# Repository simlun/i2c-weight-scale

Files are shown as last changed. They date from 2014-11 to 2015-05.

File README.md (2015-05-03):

I²C Weight Scale
================

_I²C Weight Scale: strain gauges in a Wheatstone bridge amplified in an
instrumentation amplifier, A/D converted and made available over I²C in a PIC
microcontroller._

I²C slave. Reading from the slave responds with a stable digital representation
of the load on the strain gauges under a hacked ordinary weight scale.

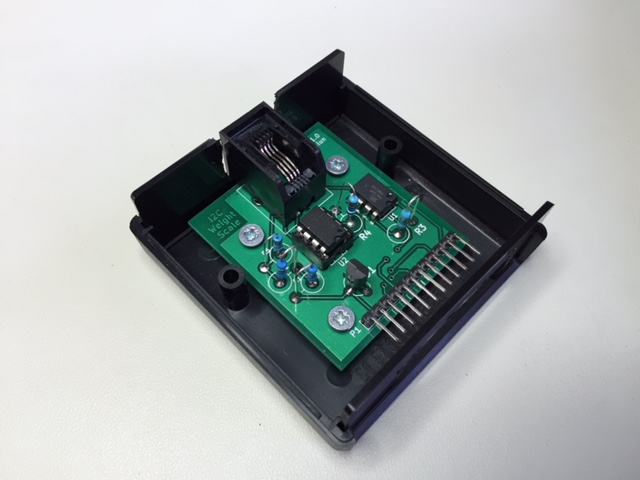
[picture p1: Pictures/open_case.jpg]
Open Case


Schematic
---------

The [KiCad](http://www.kicad-pcb.org/) source files can be found under `PCB/`.
The schematic rendered as a PDF is reached by clicking the PNG below.. The
KiCad project depends on [my component library](https://github.com/simlun/kicad-library-by-simlun)
which should be checked out alongside this repository.

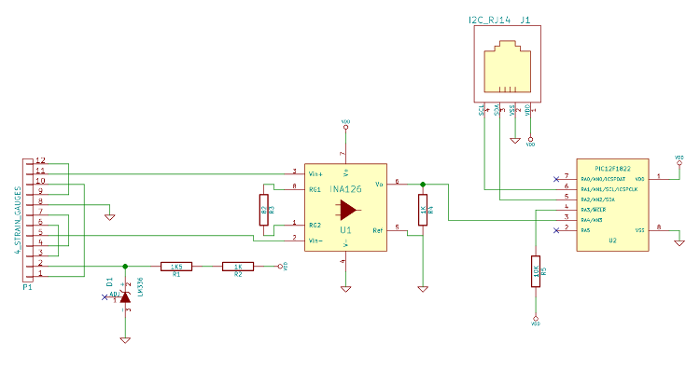
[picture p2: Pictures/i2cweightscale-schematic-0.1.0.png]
Schematic


Hacked Weight Scale
-------------------

Simply buy a cheap kitchen weight scale, remove its PCB and instead take the
4x3=12 leads from the 4 strain gauges to create an external port from a 2.54 mm
pin header.

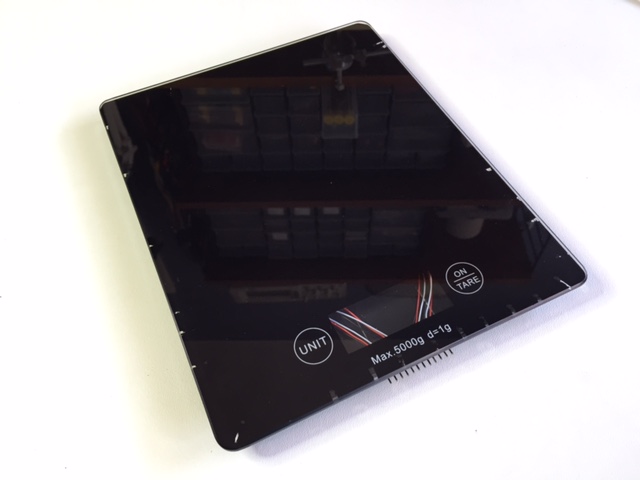
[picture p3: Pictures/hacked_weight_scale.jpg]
Hacked Weight Scale


The I²C Weight Scale PCB is a module that can connect to any weight scale of 4
strain gauges.

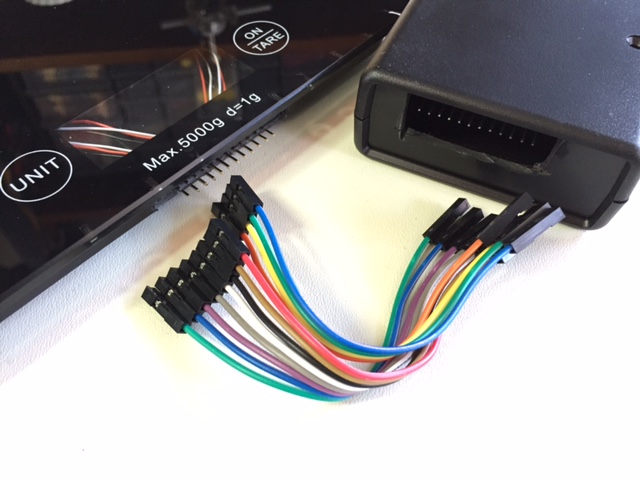
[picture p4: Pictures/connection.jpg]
Connection


License
-------



This work is licensed under the Creative Commons Attribution-ShareAlike 4.0
International License. To view a copy of this license, visit
http://creativecommons.org/licenses/by-sa/4.0/ or send a letter to Creative
Commons, PO Box 1866, Mountain View, CA 94042, USA.

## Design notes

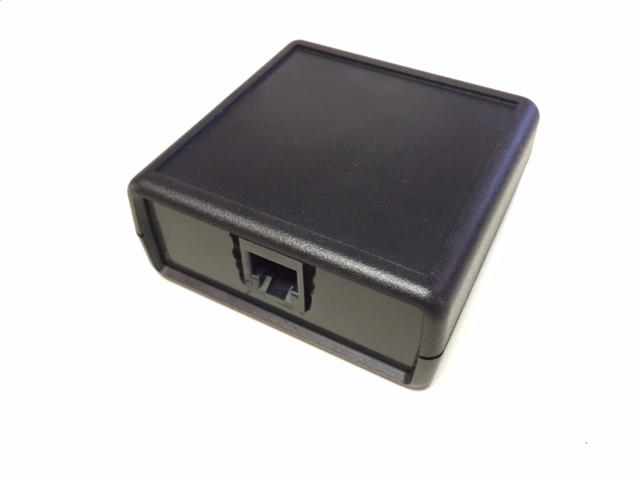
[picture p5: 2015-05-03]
Pictures/closed_cas.jpg

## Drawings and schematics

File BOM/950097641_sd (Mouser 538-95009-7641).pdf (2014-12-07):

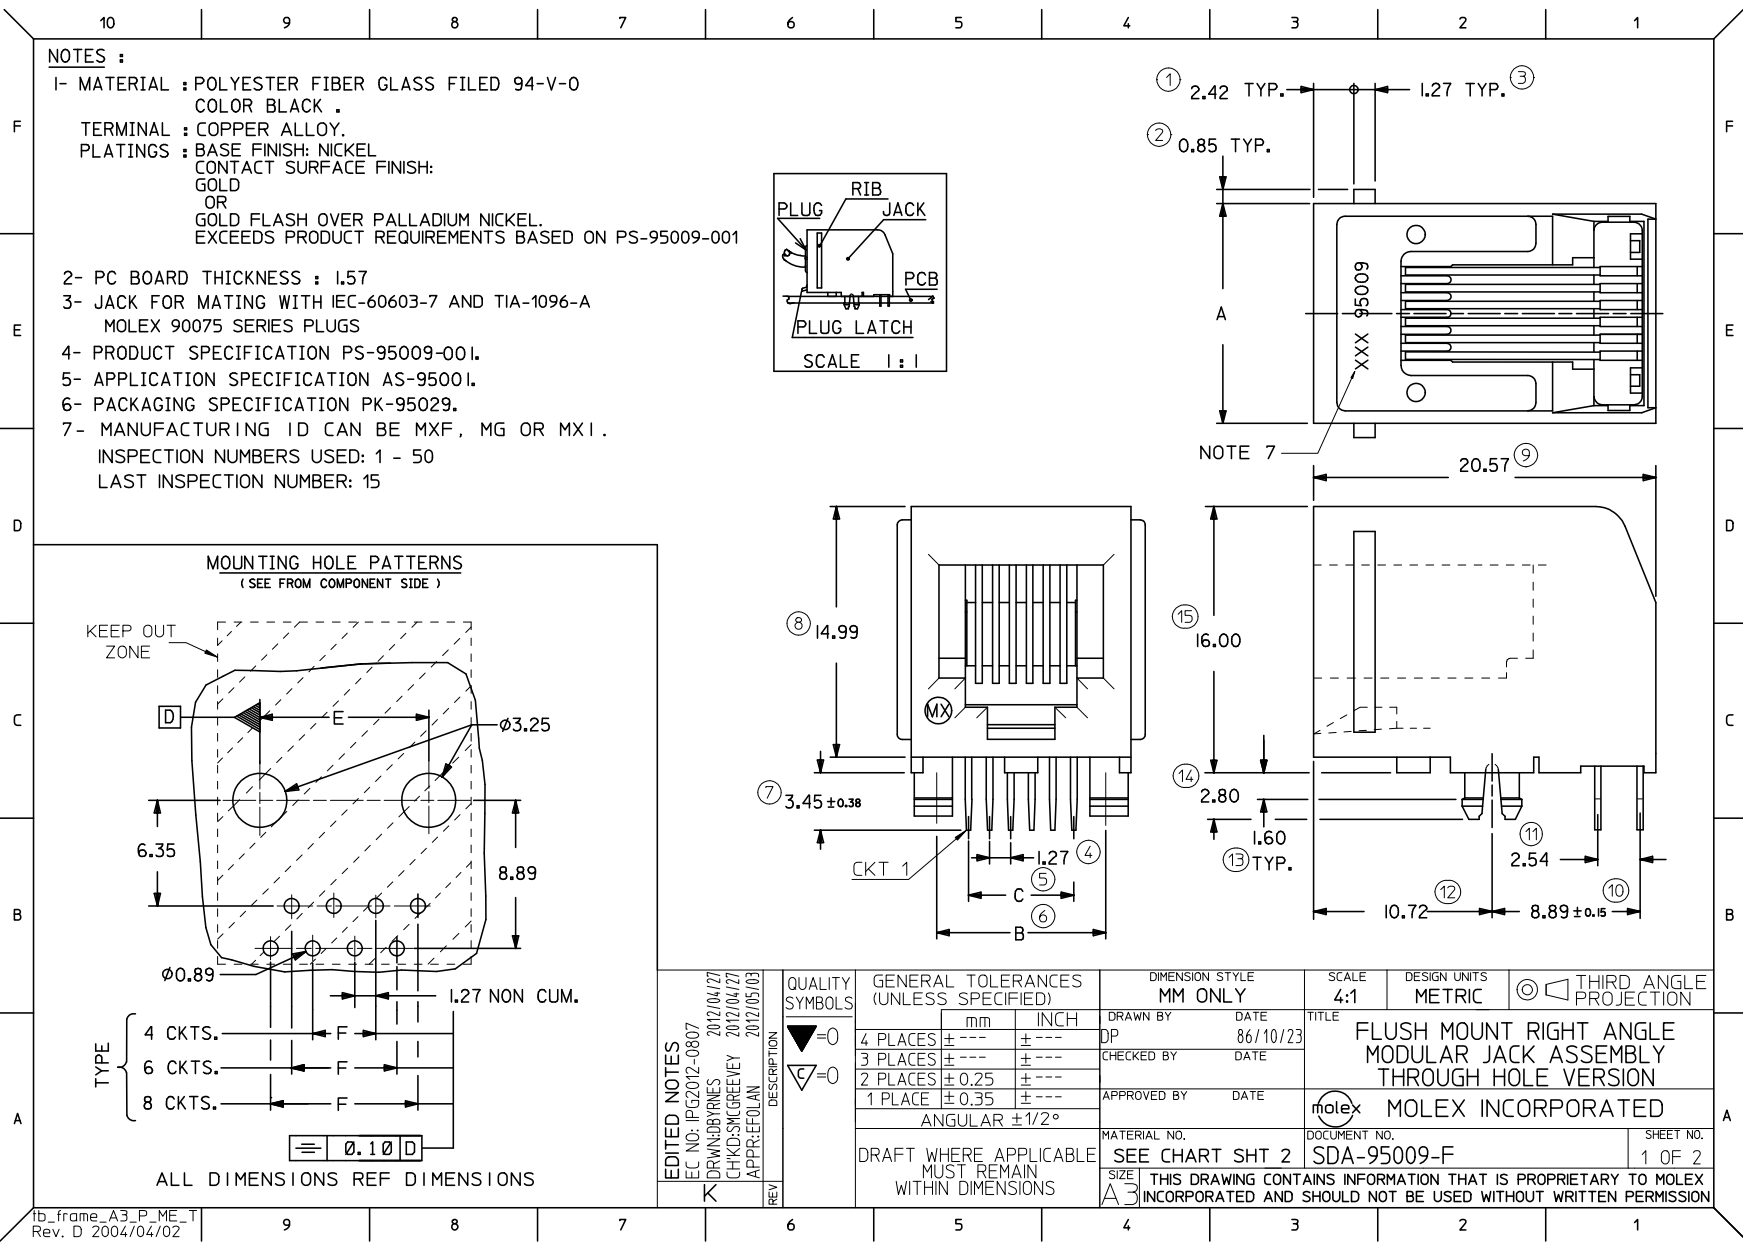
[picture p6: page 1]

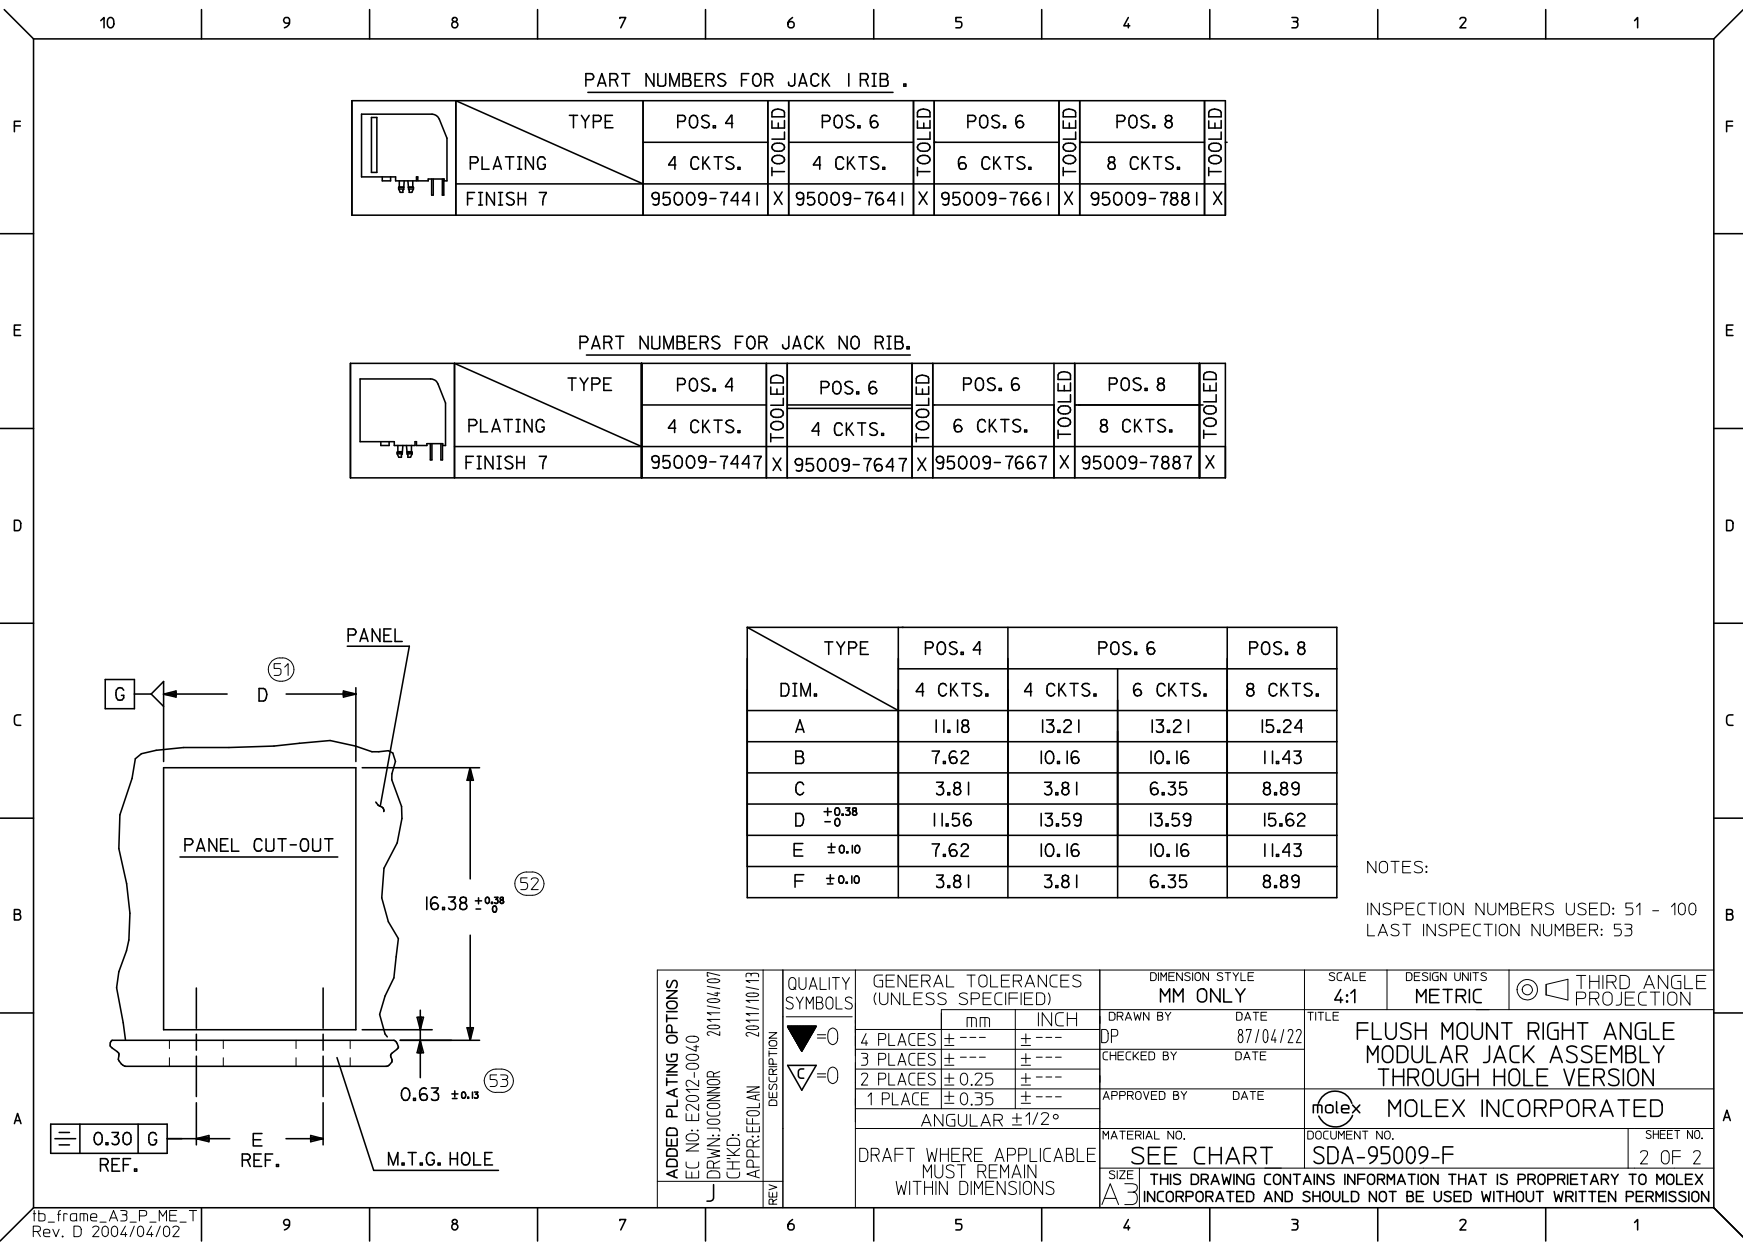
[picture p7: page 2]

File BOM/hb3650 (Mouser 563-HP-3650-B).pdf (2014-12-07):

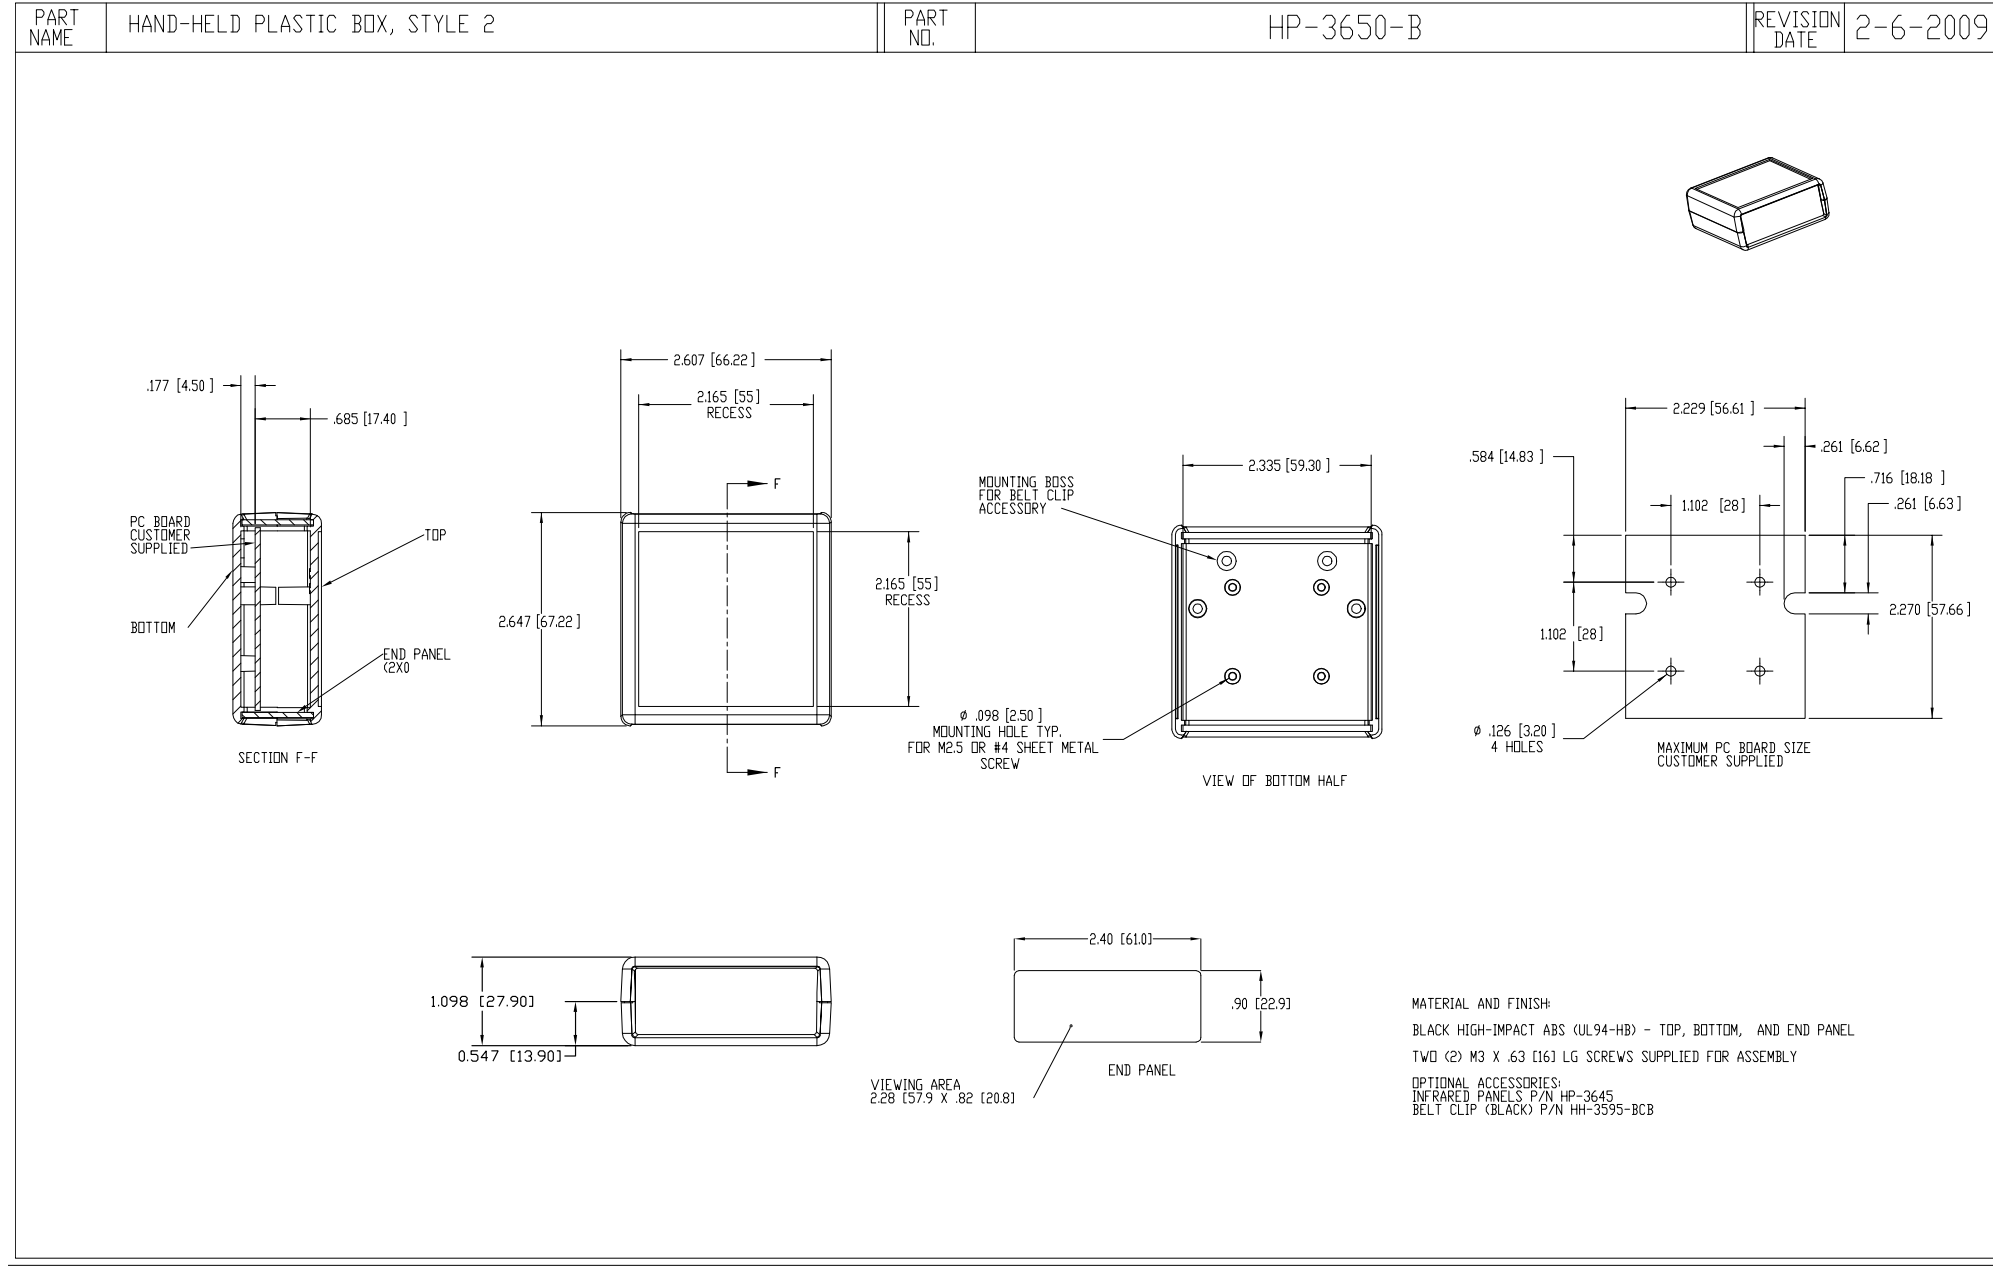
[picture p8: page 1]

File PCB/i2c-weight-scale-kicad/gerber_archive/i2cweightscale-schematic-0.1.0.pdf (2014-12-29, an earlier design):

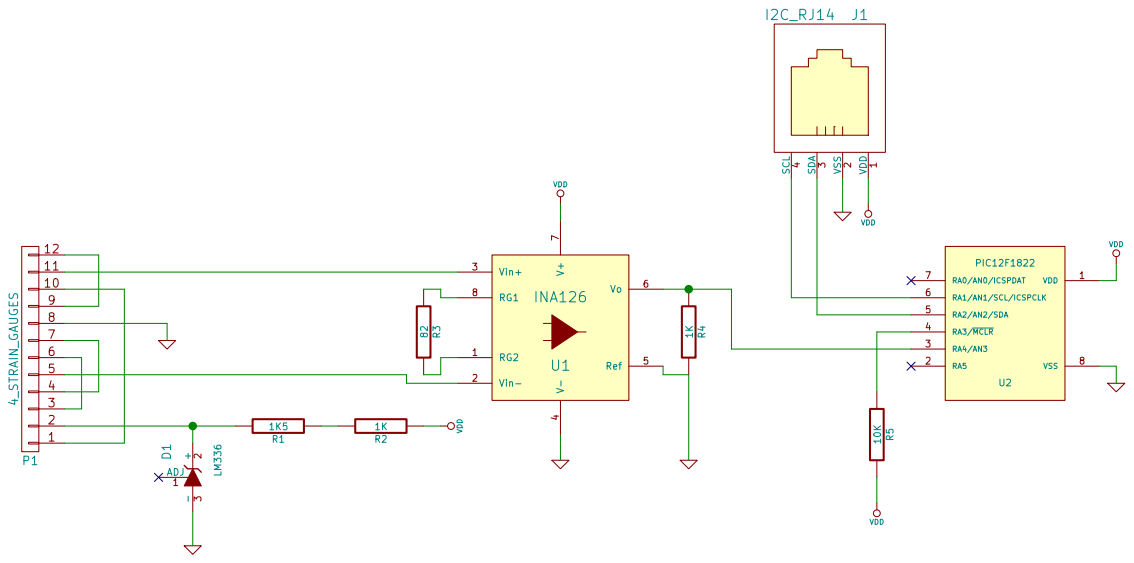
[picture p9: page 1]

File: i2c-weight-scale-kicad.sch Sheet: / Simon Lundmark

Id: 1/1 Title: I2C Weight Scale

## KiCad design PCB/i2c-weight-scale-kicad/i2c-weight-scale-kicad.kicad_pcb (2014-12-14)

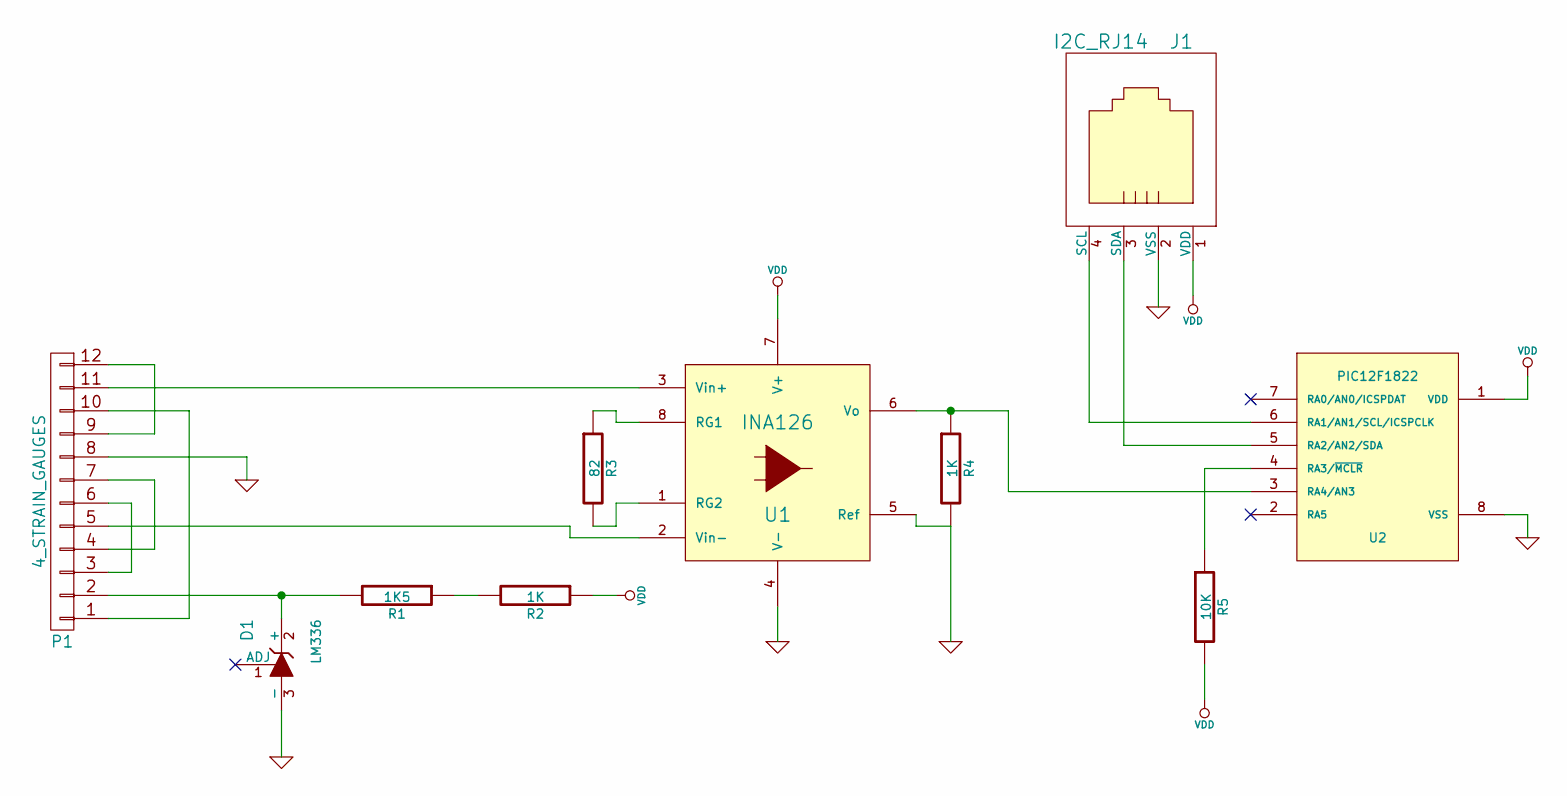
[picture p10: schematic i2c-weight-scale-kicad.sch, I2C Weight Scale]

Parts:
D1: LM336; TO-92-Free-molded-wide-oval
J1: I2C_RJ14; RJ14_6P4C_right_angle_Molex_95009-7641
P1: 4_STRAIN_GAUGES; Pin_Header_Straight_1x12
R1: 1K5; Resistor_Vertical_RM5mm
R2, R4: 1K; Resistor_Vertical_RM5mm
R3: 82; Resistor_Vertical_RM5mm
R5: 10K; Resistor_Vertical_RM5mm
U1: INA126; DIP-8__300
U2: PIC12F1822; DIP-8__300

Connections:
GND: D1.3 (-), J1.2 (VSS), P1.8, R4.2, U1.4 (V-), U1.5 (Ref), U2.8 (VSS)
unnamed: D1.2 (+), P1.2, R1.2
unnamed: J1.3 (SDA), U2.5 (RA2/AN2/SDA)
unnamed: J1.4 (SCL), U2.6 (RA1/AN1/SCL/ICSPCLK)
unnamed: P1.1, P1.10
unnamed: P1.3, P1.6
unnamed: P1.4, P1.7
unnamed: P1.5, U1.2 (Vin-)
unnamed: P1.11, U1.3 (Vin+)
unnamed: P1.9, P1.12
unnamed: R1.1, R2.2
unnamed: R3.1, U1.8 (RG1)
unnamed: R3.2, U1.1 (RG2)
unnamed: R4.1, U1.6 (Vo), U2.3 (RA4/AN3)
unnamed: R5.1, U2.4 (RA3/~MCLR)
VDD: J1.1 (VDD), R2.1, R5.2, U1.7 (V+), U2.1 (VDD)

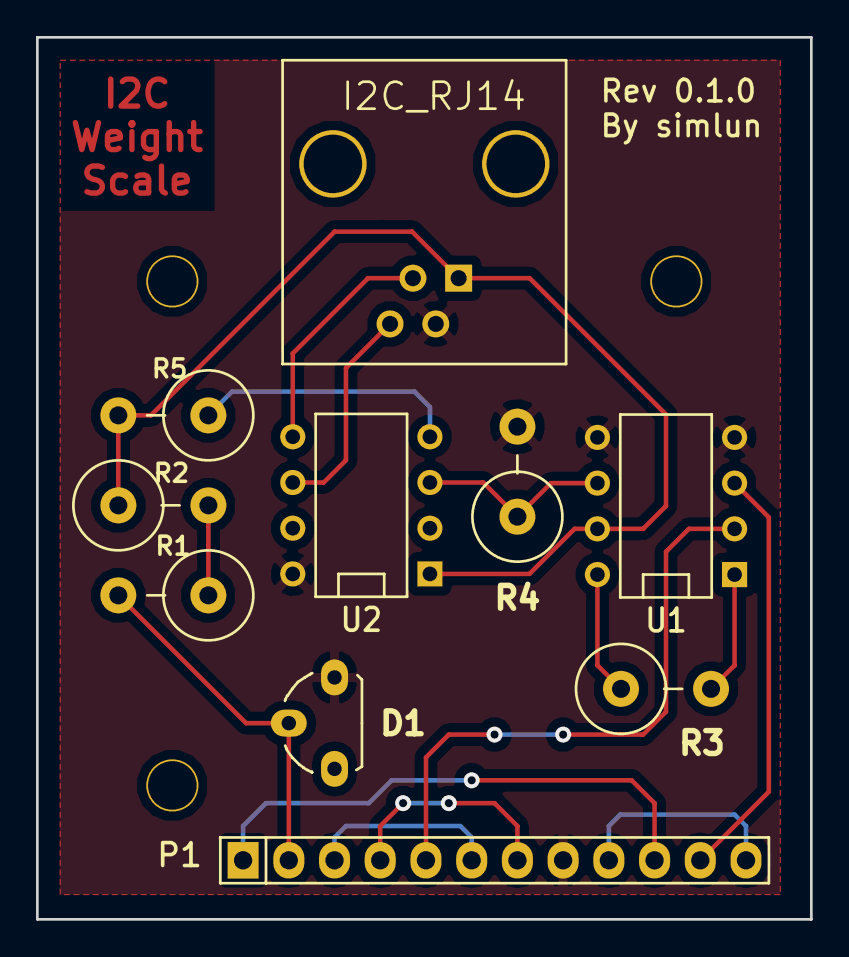
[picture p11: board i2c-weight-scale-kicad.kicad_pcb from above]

Board: 2 copper layers, 43.0 x 49.0 mm, 13 parts (0 on the bottom side), 16 nets.

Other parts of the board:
MountingHole_2-7mm, MountingHole_2-7mm#2, MountingHole_2-7mm#3: VAL**; MountingHole_2-7mm

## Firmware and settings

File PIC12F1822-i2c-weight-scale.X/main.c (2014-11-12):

// ----------------------------------------------------------------------
// Includes
#include <xc.h>
#include "pic_config.h"

#include <stdlib.h>
#include <stdint.h>

#include "i2c.h"
#include "adc.h"


// ----------------------------------------------------------------------
// Data
volatile uint16_t analog_value = 0x4711;

volatile uint16_t foo[30];
volatile uint8_t foo_index;


// ----------------------------------------------------------------------
// Configuration and initialization functions
void initialize_io(void) {
    // Set A5 pin as an output
    TRISA5 = 0;

    int i;
    for (i = 0; i < 30; i++) {
        foo[i] = 0;
    }
    foo_index = 0;
}


// ----------------------------------------------------------------------
// Logic functions
void blink_once(void) {
    PORTAbits.RA5 = 1;
    __delay_ms(25);
    PORTAbits.RA5 = 0;
}


// ----------------------------------------------------------------------
// Main
int main(void) {
    initialize_oscillator();
    initialize_io();
    initialize_voltage_reference();
    initialize_adc();
    initialize_i2c_readonly_slave(0x11);

    blink_once();

    while (1) {
        foo[foo_index] = analog_read();
        foo_index++;
        if (foo_index > 30) {
            foo_index = 0;
        }

        uint16_t tmp = 0;
        int i;
        for (i = 0; i < 30; i++) {
            tmp += foo[i];
        }
        tmp = tmp / 30;
        analog_value = tmp;
    }
}


// ----------------------------------------------------------------------
// Interrupt Service Routine
void interrupt ISR(void) {
    i2c_2_byte_master_read_request_handler(&analog_value);
}

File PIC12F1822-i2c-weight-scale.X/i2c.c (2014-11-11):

#include <xc.h>

#include <stdlib.h>
#include <stdint.h>

#include "bool.h"


// ----------------------------------------------------------------------
// Data
volatile static bit i2c_buffer_index = 0;


// ----------------------------------------------------------------------
// I2C implementation
void initialize_i2c_readonly_slave(uint8_t seven_bit_address) {
    // Set SCL and SDA pins as inputs by settings the TRIS bits (p. 229)
    TRISA1 = 1; // SCL
    TRISA2 = 1; // SDA

    // Setup MSSP as I2C slave mode, 7-bit address
    // with Start and Stop bit interrupts
    SSPCON1bits.SSPM = 0b1110;

    // Set I2C slave address
    SSP1ADDbits.SSPADD = seven_bit_address << 1;

    // Enable the MSSP module
    SSPCON1bits.SSPEN = 1;

    // Enable the MSSP interrupt
    SSP1IE = 1;

    // Enable all active peripheral interrupts
    PEIE = 1;

    // Enable all active interrupts
    GIE = 1;
}

bool is_i2c_read_operation_and_last_bit_was_an_address_byte(void) {
    // "State 3" from the Microchip application notes AN734
    // S = 1, D_A = 0, R_W = 1
    return (SSP1STATbits.S == 1 && SSP1STATbits.D_nA == 0 && SSP1STATbits.R_nW == 1);
}

bool is_i2c_read_operation_and_last_byte_was_a_data_byte(void) {
    // "State 4" from the Microchip application notes AN734
    // S = 1, D_A = 1, R_W = 1, BF = 0
    return (SSP1STATbits.S == 1 && SSP1STATbits.D_nA == 1 && SSP1STATbits.R_nW == 1 && SSP1STATbits.BF == 0);
}

/*
 * Take a 16 bit source value and return the first 8 bits the first time this
 * function is called, then return the last 8 bits the second time. The source
 * value is stored and ignored for the second function call to protect it from
 * getting inconsistent if the source changed in between calls.
 *
 * Useful for sending an uint16_t over I2C in two subsequent 8-bit writes.
 */
uint8_t chunked(uint16_t source) {
    volatile static uint16_t my_source;

    if (i2c_buffer_index == 0) {
        my_source = source;
    }

    uint8_t chunks[2];
    chunks[0] = my_source >> 8;
    chunks[1] = (my_source << 8) >> 8;

    uint8_t return_value = chunks[i2c_buffer_index];

    i2c_buffer_index = !i2c_buffer_index;

    return return_value;
}

void i2c_write(uint8_t data) {
    // The "WriteI2C" subroutine from the Microchip application notes AN734
    // converted into C code

    // Wait for buffer to be empty
    while (SSP1STATbits.BF == 1);

    // Write data
    SSP1CON1bits.WCOL = 0;
    do {
        SSP1BUF = data;
    } while (SSP1CON1bits.WCOL == 1);

    // Release the clock, we are done
    SSP1CON1bits.CKP = 1;
}

void i2c_2_byte_master_read_request_handler(volatile uint16_t * data_to_send_to_master) {
    if (SSP1IF == 1) {
        SSP1IF = 0;

        if (is_i2c_read_operation_and_last_bit_was_an_address_byte()) {
            // Read address from buffer, clearing BF
            unsigned char tmp = SSP1BUF;
            i2c_buffer_index = 0;
            i2c_write(chunked(*data_to_send_to_master));
        } else if (is_i2c_read_operation_and_last_byte_was_a_data_byte()) {
            i2c_write(chunked(*data_to_send_to_master));
        }
    }
}

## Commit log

2014-11-03 Add Bill Of Materials documentation
2014-11-03 Hello, world (blinking LED on pin 2)
2014-11-05 WIP: Started implementing an I2C slave
    - Currently an Electric Imp I2C master can successfully read one byte!
2014-11-08 Read 16 bits over I2C in two 8-bit I2C reads from a master
2014-11-08 Read 2 bytes over I2C in a single 2-byte I2C read from a master
2014-11-09 Refactoring and improved I2C implementation
2014-11-09 Fix compilation warning
    - "illegal conversion between pointer types"
    [i2c.c]
2014-11-11 Implement analog/digital conversion on pin 3
    - And let the I2C master read this 10 bit value!
    - Next up: decrease the impact of input noise by implementing some kind
    of moving average.
    [adc.c, i2c.c, main.c]
2014-11-12 Tweak the voltage reference and implement moving average
    - Next step: moving mean instead
2014-11-30 WIP: Start working on a PCB layout
    [i2c-weight-scale-kicad.kicad_pcb, i2c-weight-scale-kicad.sch]
2014-12-04 Complete the load cell and amplification schematic
    [i2c-weight-scale-kicad.sch]
2014-12-04 Add RJ14 and PIC12F1822 components
    [i2c-weight-scale-kicad.sch]
2014-12-06 Tweak electrical type to pass the electrical rule check
    [i2c-weight-scale-kicad.sch]
2014-12-06 Clean up power pins, use VDD instead of +5V
    [i2c-weight-scale-kicad.sch]
2014-12-06 Assign footprint to the LM336
2014-12-06 Assign footprints to resistors and ICs
    [i2c-weight-scale-kicad.sch]
2014-12-06 Associate last component with a custom footprint
    [i2c-weight-scale-kicad.sch]
2014-12-07 Add RJ14 connector and enclosure to BOM
2014-12-07 Add all footprints and draw PCB edge cuts
    [i2c-weight-scale-kicad.kicad_pcb]
2014-12-07 Add mounting holes
    [i2c-weight-scale-kicad.kicad_pcb]
2014-12-07 Rough footprint placements on the PCB
    [i2c-weight-scale-kicad.kicad_pcb]
2014-12-08 Place the RJ14 connector on the PCB
    [i2c-weight-scale-kicad.kicad_pcb]
2014-12-08 Move origins to upper left corner of PCB
    [i2c-weight-scale-kicad.kicad_pcb]
2014-12-08 RJ14: Account for a PCB edge setback of 1.27 mm
    [i2c-weight-scale-kicad.kicad_pcb]
2014-12-08 General PCB component placements
    [i2c-weight-scale-kicad.kicad_pcb]
2014-12-08 Smarter resistor placement
    [i2c-weight-scale-kicad.kicad_pcb]
2014-12-08 Strain gauge connector traces done
    [i2c-weight-scale-kicad.kicad_pcb]
2014-12-09 Connect all nets and GND copper fill top and bottom
    [i2c-weight-scale-kicad.kicad_pcb]
2014-12-13 Remove mechanical holes
    [i2c-weight-scale-kicad.kicad_pcb]
2014-12-13 Create new mounting holes
    [i2c-weight-scale-kicad.kicad_pcb]
2014-12-14 Add text
    [i2c-weight-scale-kicad.kicad_pcb]
2014-12-14 Version 0.1.0 ready for fab
    [i2c-weight-scale-kicad.kicad_pcb]
2014-12-29 Add schematic PDF to version 0.1.0
